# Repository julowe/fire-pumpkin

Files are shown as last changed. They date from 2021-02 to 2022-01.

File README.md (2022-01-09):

# Fire Breathing Pumpkin!

Wherein we hook up a motion sensor to a servo which is mounted on a hairspray can, stick it in a spooooky pumpkin, put a tealight in front of it, and make **really** sure not to burn anyone.

## Results

Because fire.

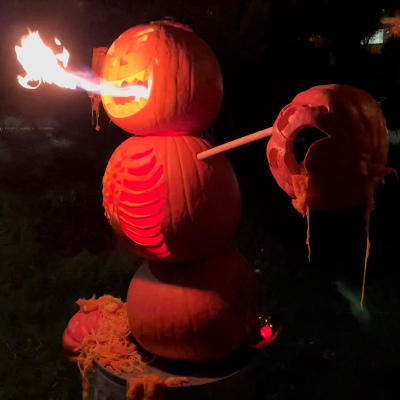
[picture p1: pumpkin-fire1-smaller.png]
Fire Breathing Pumpkin


Also see [larger version of above image](pumpkin-fire1-small.png), [another example of fire breathing](pumpkin-fire2-small.png), and [a short movie of it](pumpkin-fire-breathing-quick.mov).

## Current Version - Servo Driven

The root of this repo includes the arduino code to move a servo when triggered by a PIR sensor or a button, an STL file of a model that holds a servo and a can of hairspray, and the SCAD file for that model so you can edit dimensions if needed. Specific BOM is below.

The code and model are fairly simple. Code mostly cobbled together from product examples. Holder has the can angled in and friction fit, has 4 holes in the bottom to nail holder into a pumpkin/whatever. I left it up to you to deal with placement of arduino and wiring. And also left it to you to figure out flame/ignition source and placement. I used a tea light, as I didn't have the time to experiment with electronic sparkers/ignition options. A tea light doesn't work all that well, but I'd rather the flame go out (usual failure mode) and this all fail to ignite, rather than it igniting too much/often... As a starting point, I found the best placement of a tea light to be roughly 1.5" below nozzle, and 3" away from nozzle. 

### Bill Of Materials

The 3D printed holder only depends on the dimensions fo the servo and hairspray can. I called out dimensions of both objects in the scad file, so it should be easy enough to change them, but buy the below if you just want to use the included stl file.

| Item | Description/Comments | Link |
| --- | --- | ---- |
| Hairspray | Tresemme Hairspray can, 1.5oz travel size | [Target](https://www.target.com/p/tresemme-tres-two-extra-hold-hairspray-travel-size-1-5oz/-/A-13294119) |
| Servo | Tower Pro SG92R Microservo | [Adafruit](https://www.adafruit.com/product/169) |
| Arduino | Arduino Uno used, but only three IO pins are used so almost any version should be fine |  |
| PIR Sensor | Bought long ago from Radioshack, soo... Parallax Passive Infrared (PIR) Sensor, Rev B, SKU 555-28027 | [Parallax](https://www.parallax.com/product/pir-sensor-with-led-signal/) |
| Breadboard | or any other means of connecting wires |  |
| Button & Resistor | if you want fire on demand w/o waving your hand in front of PIR |  |

## Build

SCAD file included if you want to make any changes, but STL should suit most just fine. How to 3d print in general is out of scope of this readme, but model was designed to print with the common plane of the rectangular servo holder 'back' and 'side' of can holder flat on build plate (YZ Plane in openscad view) and with some supports recommended for underside lip of can holder. Image below shows assembled holder, in the mentioned printing orientation.

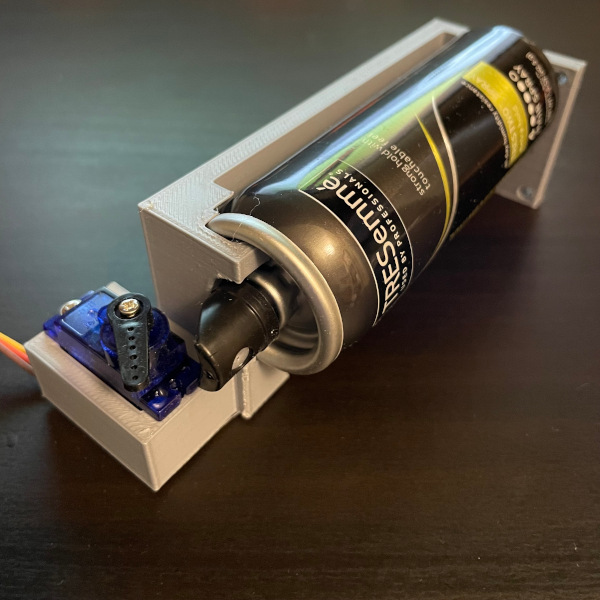
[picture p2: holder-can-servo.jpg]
3D Printed Holder


Wiring diagram shows set up of various pieces to work with included ino file/arduino code.

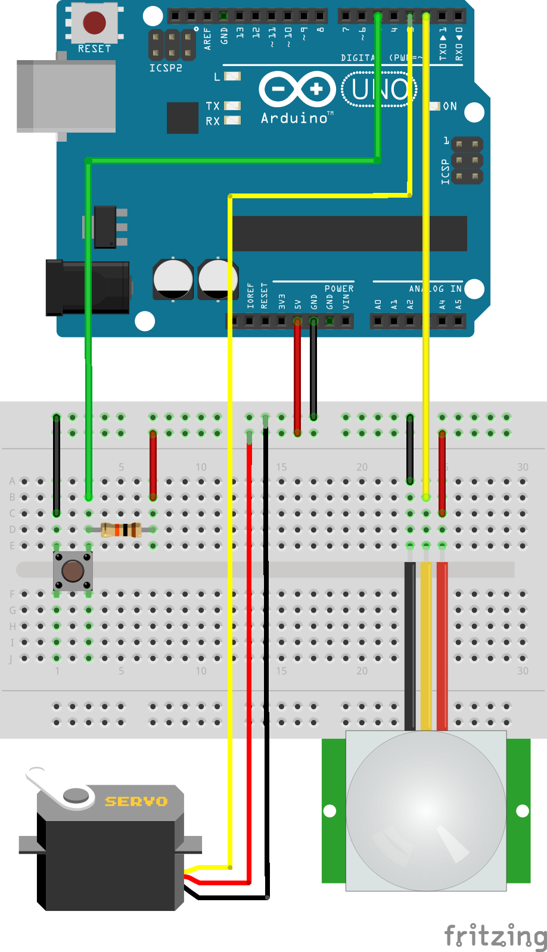
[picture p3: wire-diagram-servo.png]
Wiring Diagram


## First Version - with Glade Dispenser

I had just enough pieces to hack something together the day of Halloween. And even found a pumpkin spice glade scented can! (For pumpkin scented flaming breath) I also added a button to manually trigger the flame breath, because.

The Glade Air Freshener dispenser worked pretty well, but I wanted more fire, for longer. I've moved all glade dispenser related files to a sub directory. The wiring diagram and code is unfortunately not tested - I'm not sure if the code is the final version, and I recreated the wiring diagram from memory and this code version.

I will hopefully be able to clean up my mess of a first version so you can still do this with easy enough to find and assemble parts (just a Glade Air Freshener, motion sensor, and an arduino - no 3d printer needed).

Also, if you don't want to do any electronics work, you can just connect wires to the Glade dispenser as I did, but then simply run them back to your apt/house and then just touch the bare ends together - viola, remote fire button. You probably don't even need to solder the wires to the button in the Glade dispenser, alligator clips might work?

## Other Versions

The code was originally copied from [Richard Osgood's version from the WayBack Machine](https://web.archive.org/web/20131106091413/http://www.richardosgood.com/blog/wp-content/uploads/2013/10/fireLantern_v1.ino), but I actually ended up not using any as I had a motion sensor, not a distance sensor. Code checked in to maintain a copy of it and to acknowledge the inspiration. A [great Youtube video is available](https://www.youtube.com/watch?v=qDRTbuhs05Q) showing his build process.

I recently saw [Markus Haack's version here](https://github.com/mhaack/halloween-pumpkin-fire) which is quite neat - uses wifi, MQTT, and wood/metal parts instead of 3d printing. I may look at this for remote operation (wifi vs bluetooth), but we'll see if that comes to pass at all.

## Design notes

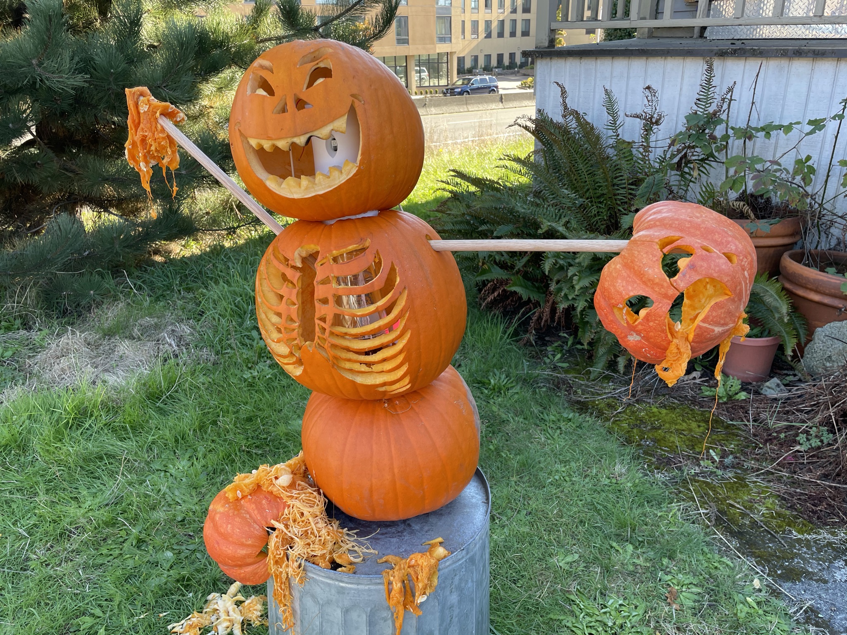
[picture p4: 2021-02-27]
pumpkin-full-daytime.jpeg

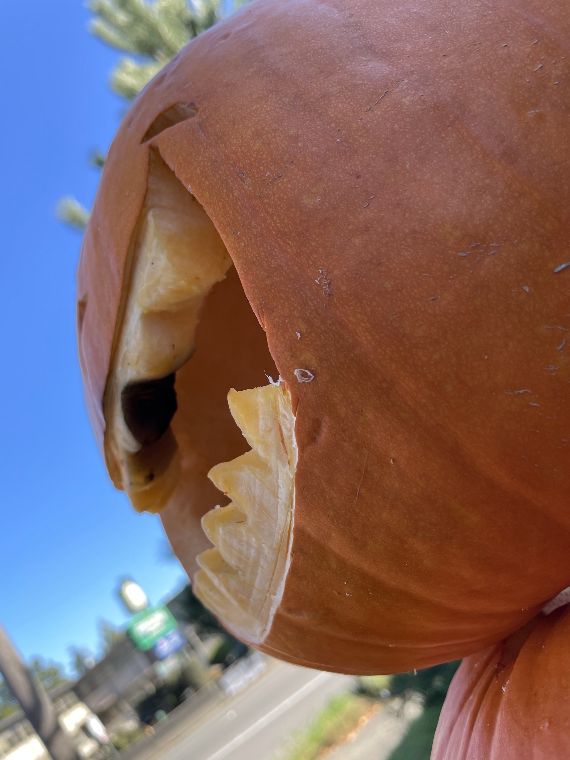
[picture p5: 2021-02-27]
pumpkin-singed.jpeg

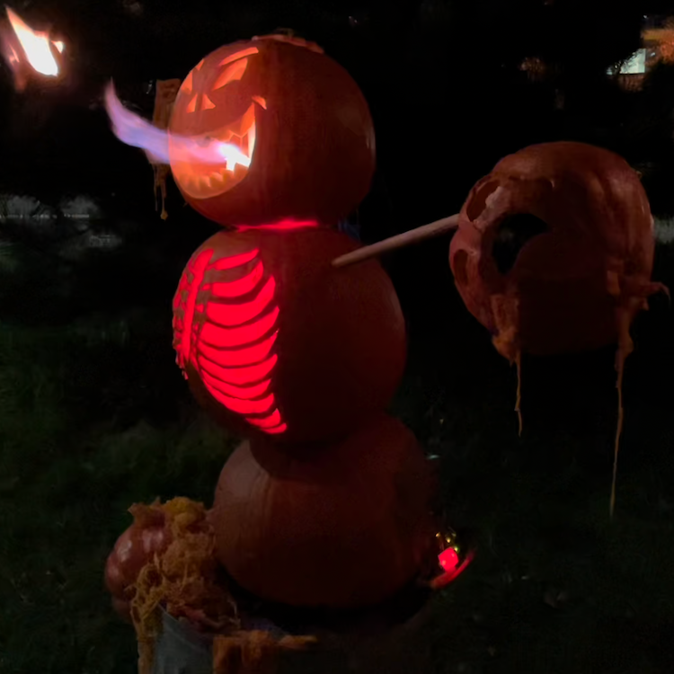
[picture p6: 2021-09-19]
pumpkin-fire2-small.png

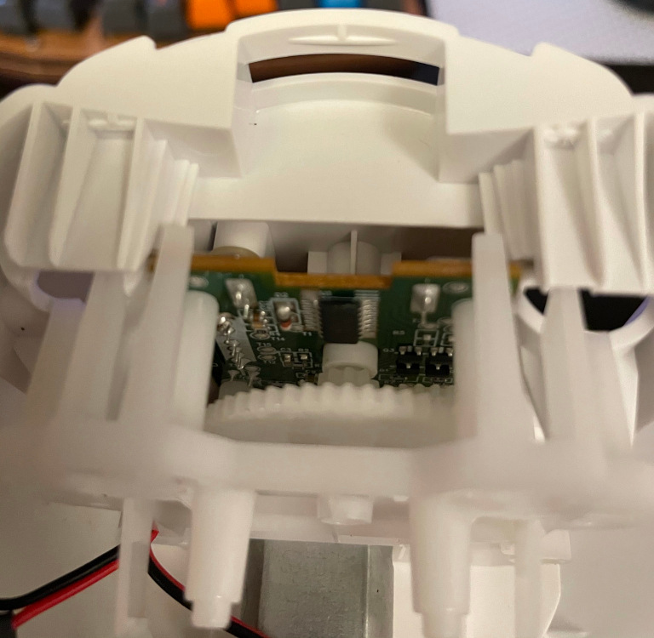
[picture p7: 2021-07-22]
glade-dispenser/glade-gears2.JPEG

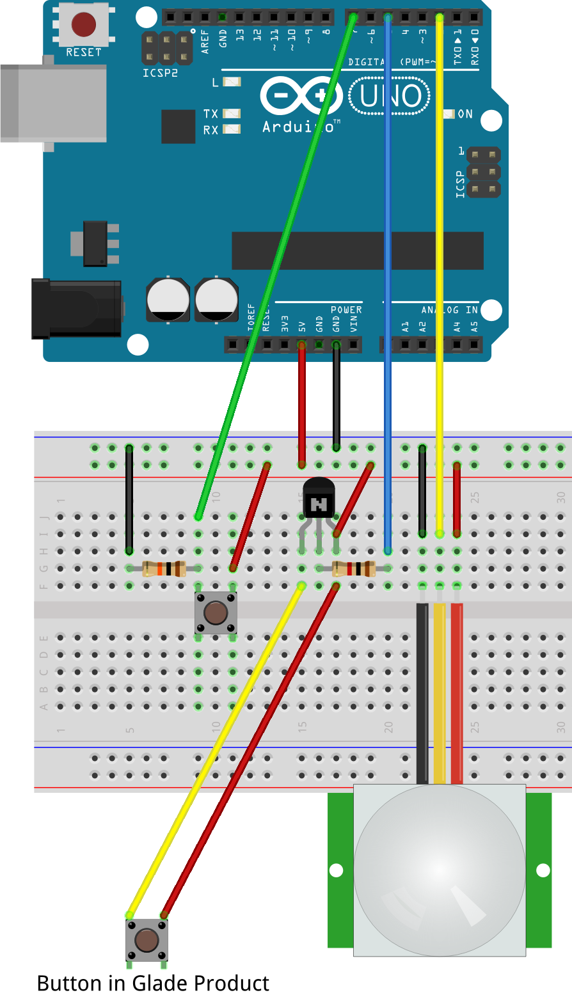
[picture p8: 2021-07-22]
glade-dispenser/wire-diagram-glade.png

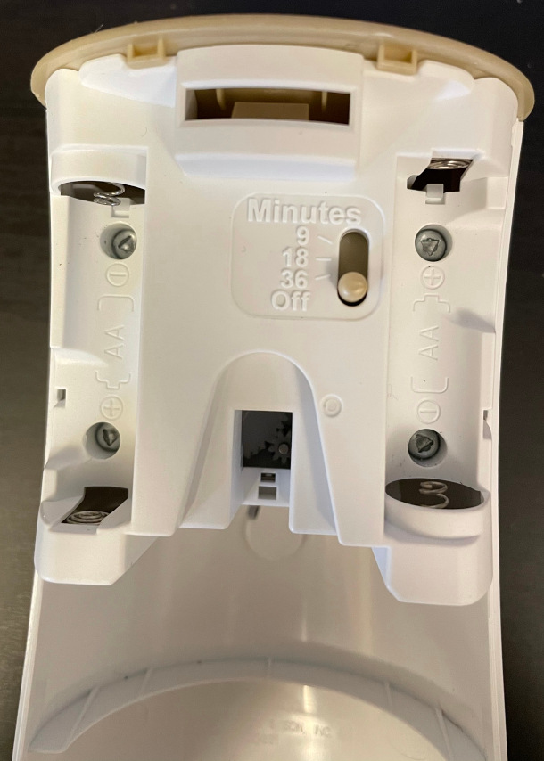
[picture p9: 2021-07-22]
glade-dispenser/glade-battery-holders.JPEG

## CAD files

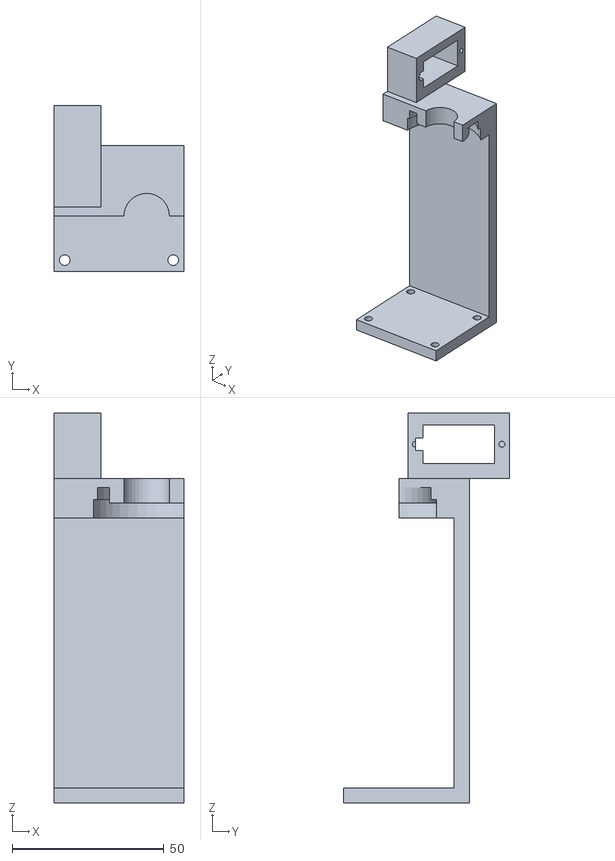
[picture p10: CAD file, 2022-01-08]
flame-breathing.stl
42.8 x 54.8 x 128.6

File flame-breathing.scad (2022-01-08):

//flamebreathing
//justin lowe 20210722

//generic holder for thing to make flame

draftingFNs = 36;
renderFNs = 180;
$fn = draftingFNs;

//Potential TODO: 
// -arduino mount - back of mount? Likely better if arduino board is not connected to this, so we don't have to worry about balance or overall placement of this mount inside pupmkin

/*Description of 3d model
-xy plane will be the top of metal part of can. so nozzle on positive side. nozzle centered on z axis.
-half ring with lip to hold can in place on top.
-servo cutout, at appropriate place relative to nozzle
*/
/*Design Choices
-This mount holds can and servo. Does not have tea light or sparker holder, mostly for time, partly to allow for more flexible placements
-servo is well mounted with just one screw, at back edge away from nozzle
-does not have arduino mount - would possibly unbalance it, also too many different form factors to consider
-best placement of tea light was found to be roughly 1.5" below nozzle, and 3" away from nozzle. Still didn't work great :-/ But I guess I'd rather it fail to ignite, than fail to not ignite/stop...
-print with the common plane of servo holder 'back' and 'side' of can holder flat on build plate (YZ Plane in openscad view) Some supports recommended for lip of can holder
*/
/* Bill Of Materials
-Tresemme Hairspray can, 1.5oz travel size, bought at Target
-servo, used Tower Pro SG92R Microservo - https://www.adafruit.com/product/169
//the rest doesn't interact with this model/holder, but fyi:
-arduino, only three IO pins used so almost any should be fine, could go down to two pins. Arduino Uno used in this instance.
-Passive Infrared (PIR) Sensor - bought long ago from Radioshack, soo... Paralax PIR Sensor, Rev B, SKU 555-28027 https://www.parallax.com/product/pir-sensor-with-led-signal/
    -other PIR sensors shoudl work, but arduino code may need to be changed
-breadboard
-button and resistor, if you want fire on demand w/o waving your hand in front of PIR.
*/
//


//// properties of physical objects
// hairspray can, specifically tresemme 1.5oz travel size
canTopOuterDiameter = 32.5; //actual
canTopInnerDiameter = 24.6; //actual
canBodyDiameter = 35; //actual
canHeight = 99; //98; //actual
canTopLipInnerDepth = 5; //5.5; //actual
canTopLipOuterDepth = 4; //3.75; //actual
nozzleDiameter = 15; //room for nozzle to rotate forward & down when pressed //13.5; //actual, about 1mm larger than metal can part below it
nozzleHeight = 15;  //actual, height of nozzle plus a tiny bit of the stem above can top

// servo
servoWidth = 23.5; //22.7; //actual
servoHeight = 12.6; //actual 12.6 at rear by wires, 11.9 by servo arm...
servoDepthBehindEars = 15.5; //actual //IDEA: how much can I shorten this, before servo housing starts to torque when arm depresses? Or is it worth it to have wide base here, so leave this?
servoDepthEarsToWires = 9.75; //actual
servoWiresWidth = 2.5;  //1.75; //actual //IDEA - could angle this channel so there is more material for screw (holding servo in) to grip at forward edge, but still not crimping wires at back edge
servoWiresHeight = 4; //actual
servoDepthTopToBottomOfEars = 7; //actual
servoCenterArmToBottomEars = 15.5; //actual, ie how far to the side to place servo to line up servo arm with nozzle
servoArmLength = 16;
servoMountingScrewInnerShaftDiameter = 2; //1.6; //actual-ish wasn't too bad but sides did buldge some
servoMountingScrewInnerShaftLength = 7.5; //actual-ish
servoMountingHoleHorizontalInset = 2.5; //actual


//// properties of holder/model
platformCanTopHeight = 3;
platformCanTopHorizontalPadding = 2; //how far for retention block to go past can diameter
platformCanBottomHeight = 5;
holderBackplaneDepth = 5;
servoHolderVerticalPadding = 4;
servoHolderHorizontalPadding = 5;
servoArmHorizontalSetback = nozzleDiameter/2; //half nozzle diameter?
servoHorizontalSetback = 8; //measured rough placement, y direction movement
servoHorizontalShift = 15; //x direction movement
servoVerticalAdjustment = 5; //rough measurement of how far above top of can should the bottom of the servo housing be, in order to hit the nozzle well
platformCanBottomMountingHoleDiameter = 3.5; //meh?

modelCutoffWidth = 6; //this is what removes material from side of holder - currently chosen to align closely wiht inner ring of can holder, could likey be less and still hold can in well but was considering stabilty of base


difference(){
    union(){
        //holds on to top of can around nozzle and inside lip of can
        difference(){
            //portion to go into/around lip of can
            translate([(canTopOuterDiameter/2+platformCanTopHorizontalPadding)/2-(servoHorizontalShift+servoDepthBehindEars)/2,(canTopOuterDiameter/2+platformCanTopHorizontalPadding)/2,-canTopLipInnerDepth+platformCanTopHeight/2]){
        
                cube([(servoHorizontalShift+servoDepthBehindEars)+canTopOuterDiameter/2+platformCanTopHorizontalPadding,canTopOuterDiameter/2+platformCanTopHorizontalPadding,canTopLipInnerDepth*2+platformCanTopHeight],true);
            }
            
            //remove can area
            makeCanTresemme(); 
        } //end difference of cube to can to hold on to top of can
        
        //backplane of holder
        translate([(canTopOuterDiameter/2+platformCanTopHorizontalPadding)/2-(servoHorizontalShift+servoDepthBehindEars)/2,holderBackplaneDepth/2+(canTopOuterDiameter+platformCanTopHorizontalPadding*2)/2,platformCanTopHeight/2-(canHeight+platformCanBottomHeight)/2]){
            cube([(servoHorizontalShift+servoDepthBehindEars)+canTopOuterDiameter/2+platformCanTopHorizontalPadding,holderBackplaneDepth,platformCanTopHeight+canHeight+platformCanBottomHeight],true);
        }
        
        //bottom of holder
        translate([(canTopOuterDiameter/2+platformCanTopHorizontalPadding)/2-(servoHorizontalShift+servoDepthBehindEars)/2,0,-canHeight-platformCanBottomHeight/2]){
            cube([(servoHorizontalShift+servoDepthBehindEars)+canTopOuterDiameter/2+platformCanTopHorizontalPadding,canTopOuterDiameter+platformCanTopHorizontalPadding*2,platformCanBottomHeight],true);
        }
        
        //servo holder
        difference(){
            //cutout for servo body
            translate([-servoHorizontalShift-(servoDepthBehindEars)/2,(servoWidth/2)+servoHorizontalSetback,(servoHeight)/2+platformCanTopHeight+servoVerticalAdjustment]){
                difference(){
                    translate([0,0,(servoHolderVerticalPadding-servoVerticalAdjustment)/2]){
                    cube([servoDepthBehindEars,servoWidth+servoHolderHorizontalPadding*2,servoHeight+servoHolderVerticalPadding+servoVerticalAdjustment],true);
                    }
                    //main cutout for servo body
                    cube([servoDepthBehindEars,servoWidth,servoHeight],true);                 
                }//end difference for cutout for servo body
            }
            
            //forward side servo mounting hole
            translate([-servoHorizontalShift,servoHorizontalSetback-servoMountingHoleHorizontalInset,(servoHeight)/2+platformCanTopHeight+servoVerticalAdjustment]){
                rotate([0,-90,0]){
                    cylinder(servoMountingScrewInnerShaftLength, servoMountingScrewInnerShaftDiameter/2, servoMountingScrewInnerShaftDiameter/2);
                }
            }
            //rear side servo mounting hole
            translate([-servoHorizontalShift,servoHorizontalSetback+servoWidth+servoMountingHoleHorizontalInset,(servoHeight)/2+platformCanTopHeight+servoVerticalAdjustment]){
                rotate([0,-90,0]){
                    cylinder(servoMountingScrewInnerShaftLength, servoMountingScrewInnerShaftDiameter/2, servoMountingScrewInnerShaftDiameter/2);
                }
            }
            
            //cutout for wires for servo body
            translate([-servoHorizontalShift-servoDepthBehindEars,servoHorizontalSetback-servoWiresWidth,(servoHeight)/2+platformCanTopHeight+servoVerticalAdjustment-servoWiresHeight/2]){
                cube([servoDepthBehindEars,servoWiresWidth*1.01,servoWiresHeight]);
            }
        } //end differnce for servo mounting holes
    }//end union of all
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

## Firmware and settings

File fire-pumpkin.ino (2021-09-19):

/*
 * Flame Breathing Pumpkin - Motion sensor or button press triggers servo to depress nozzle on can
 * mostly cribbed from simple servo example from Adafruit Arduino, and probably their PIR example too, I forget at this point
 */

/*
 MIT License

Copyright (c) 2021 Justin

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
THE SOFTWARE IS PROVIDED "AS IS", WITHOUT WARRANTY OF ANY KIND, EXPRESS OR
IMPLIED, INCLUDING BUT NOT LIMITED TO THE WARRANTIES OF MERCHANTABILITY,
FITNESS FOR A PARTICULAR PURPOSE AND NONINFRINGEMENT. IN NO EVENT SHALL THE
AUTHORS OR COPYRIGHT HOLDERS BE LIABLE FOR ANY CLAIM, DAMAGES OR OTHER
LIABILITY, WHETHER IN AN ACTION OF CONTRACT, TORT OR OTHERWISE, ARISING FROM,
OUT OF OR IN CONNECTION WITH THE SOFTWARE OR THE USE OR OTHER DEALINGS IN THE
SOFTWARE.
*/

#include <Servo.h> 

Servo servo;  
const int servoPin = 3;
const int angleMin = 20;
const int angleMax = 70; //60 deg didn't quite actuate, 70 does quite well
const int sweepSmoothing = 15;
const int timePIRdepressNozzle = 0.5 * 1000; //X seconds
const int minTimeBetweenActuation = 5 * 1000; //X seconds
int angle = angleMin;   // servo position in degrees
int servoArmMoving = 0;
int servoArmDown = 0;

//led indicator stuff
const int ledPin = 13;                // declare the pin for the onboard LED

//button tester stuff
const int buttonPin = 5;
int buttonPressed = 0;

//PIR motion stuff
int inputPIRPin = 2;               // choose the input pin (from PIR sensor)
//int pirState = LOW;             // we start, assuming no motion detected
int valPIR = 0;                    // variable for reading the pin status
const int secsForPIRtoSettle = 30;

void setup() 
{ 
  pinMode(ledPin, OUTPUT);      // declare LED as output
  servo.attach(servoPin);
  pinMode(buttonPin, INPUT); //declare button as input
  servo.write(angleMin);
  pinMode(inputPIRPin, INPUT);     // declare sensor signal as input

  //wait for PIR motion sensor to settle to off state and blink onboard LED so the user knows something is actually going on
  for(int counterHalfSeconds = 0; counterHalfSeconds < secsForPIRtoSettle*2; counterHalfSeconds++) {
    digitalWrite(ledPin, HIGH); // turn onBoard LED on
    delay(250);  //delay 0.25 seconds
    digitalWrite(ledPin, LOW); // turn onBoard LED on
    delay(250);  //delay 0.25 seconds
  } 
//  delay(minTimeBetweenActuation); // settle motion sensor
} 
 
 
void loop() 
{ 
  int buttonState;
  buttonState = digitalRead(buttonPin);
  
  if (buttonState == LOW) {
    if (servoArmDown == 0 && servoArmMoving == 0) {
//      buttonPressed = 1;
      nozzlePress();
    }
    //NB: No delay here so release happens exactly when you release button

  } else {
    if (servoArmDown == 1 && servoArmMoving == 0) {
      nozzleRelease();
//      buttonPressed = 0;
    }
    
    //delay(minTimeBetweenActuation); //still have a cooldown timeout, because safety?
  }

  valPIR = digitalRead(inputPIRPin);  // read input value
  if (valPIR == HIGH && servoArmDown == 0 && servoArmMoving == 0) { // check if the input is PIR sees motion/is HIGH, and if servo arm up and not moving
    //pres nozzle down with servo
    nozzlePress();
    
    //wait set time before releasing
    delay(timePIRdepressNozzle);
    
    //release nozzle with servo
    nozzleRelease();
    
    delay(minTimeBetweenActuation); //cooldown timeout
    
//    if (pirState == LOW) {
//      // we have just turned on
//      Serial.println("Motion detected!");
//      // We only want to print on the output change, not state
//      pirState = HIGH;
//    }
  }
} 

void nozzlePress() {
  // turn onBoard LED on:
  digitalWrite(ledPin, HIGH); 
  //set indicator servo arm is moving down
  servoArmMoving = 1;
  // scan from angleMin to angleMax degrees
  for(angle = angleMin; angle < angleMax; angle++)  
  {                                  
    servo.write(angle);               
    delay(sweepSmoothing);                   
  } 
  //set indicator servo arm is down, and no longer moving
  servoArmDown = 1;
  servoArmMoving = 0;
}

void nozzleRelease() {
  //set indicator servo arm is moving down
  servoArmMoving = 1;
  // now scan back from angleMax to angleMin degrees
  for(angle = angleMax; angle > angleMin; angle--)    
  {                                
    servo.write(angle);           
    delay(sweepSmoothing);       
  } 
  servo.write(angleMin); //redundant?
  //set indicator servo arm is not down, and no longer moving
  servoArmDown = 0;
  servoArmMoving = 0;
  
  digitalWrite(ledPin, LOW); // turn LED OFF
}

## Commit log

2021-01-17 new code for motion sensor
2021-02-27 full view of pumpkin in the daytime
2021-02-27 picture of singed inside pumpkin mouth
2021-03-18 rename pin for signal out to motor
2021-03-18 rename pin with signal from motion sensor
2021-07-22 wire diagram - not verified/tested!
    [wire-diagram.fzz]
2021-07-22 notes for 3d design
    [flame-breathing.scad]
2021-09-13 updated .ino with code to run servo instead of glade dispenser
2021-09-13 added glade to wiring diagram name
2021-09-13 and add glade to fritzing file
    [wire-diagram-glade.fzz]
2021-09-13 wiring diagram for servo
    [wire-diagram-servo.fzz]
2021-09-13 moved glade-dispenser related files to subdir
    [wire-diagram-glade.fzz]
2021-09-13 updated readme to relfect servo code/plan/status
2021-09-13 added longer settle period for PIR in setup, button and PIR should not both try to move servo now in edge cases
2021-09-15 full backplane holder
    [flame-breathing.scad]
2021-09-15 cutoff part of model for printing w fewer supports, code cleanup
    [flame-breathing.scad]
2021-09-19 add stills of fire breathing pumpkin
2021-09-19 tweak servo arm angle & press time
2021-09-21 some tweaks after test prints
    [flame-breathing.scad]
2022-01-08 wire-diagram: fixed one servo wire not connecting to breadboard
    [wire-diagram-servo.fzz]
2022-01-08 scad: add info on model, cleaned up comments/code
    [flame-breathing.scad]
2022-01-08 stl: adding stl of scad file, for ease
    [flame-breathing.stl]
2022-01-08 updated readme for stl/scad and BOM
2022-01-08 add image of 3d printed holder with can and servo installed
